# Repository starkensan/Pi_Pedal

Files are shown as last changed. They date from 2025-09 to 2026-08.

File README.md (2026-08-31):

# USB-MIDI-Pedal

RP2040 Zero を使用して、ギター用フットスイッチやエクスプレッションペダルから  
USB-MIDI（CC / PC）メッセージを送信できるデバイスです。  
DAW ソフトやアンプシミュレーター（Amplitube / Helix Native など）で使用できます。

## Features
- USB MIDI（CC / PC）送信対応
- フットスイッチによる CC/PC 切り替え
- エクスプレッションペダル対応（アナログ入力）
- OLED による状態表示
- ノブによる直感的な操作
- ラッチ / モーメンタリ切り替え
- デバウンス処理付き
- コンパクトな RP2040 Zero ベース
- PCB 設計データ & 3D モデル付き

## Product image

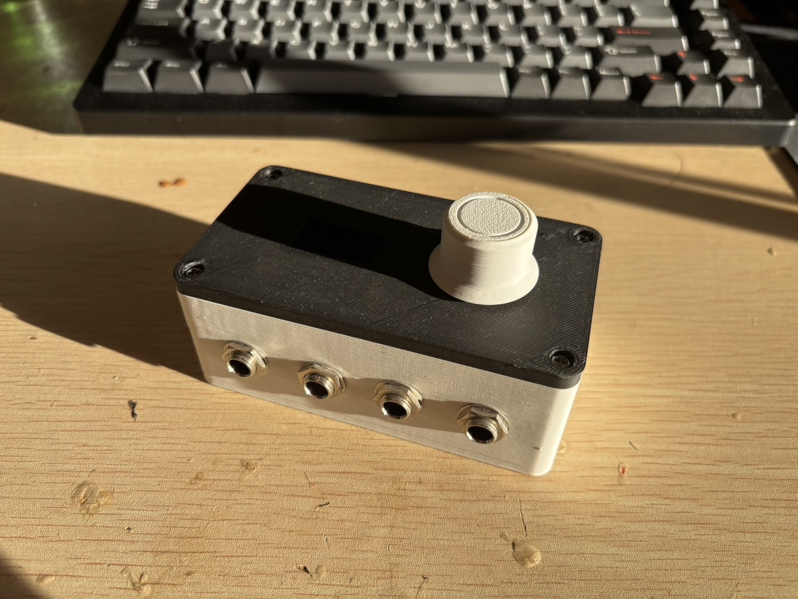
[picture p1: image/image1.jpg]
Prodct_image_1

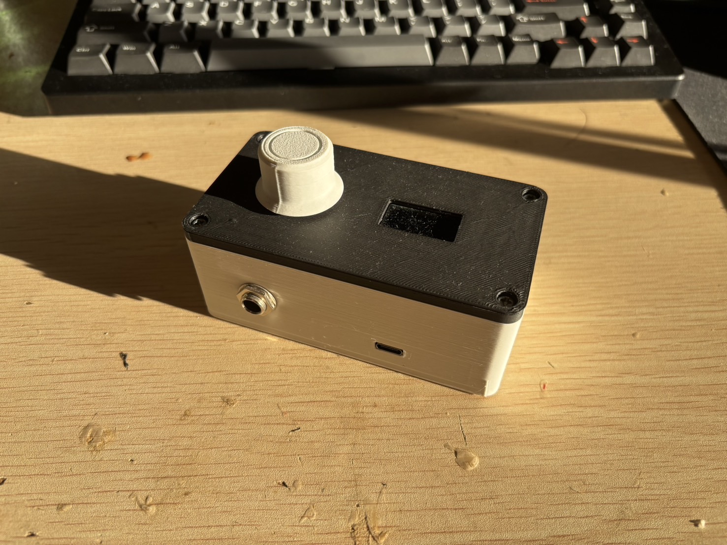
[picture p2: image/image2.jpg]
Prodct_image_2


## Hardware
- **Microcontroller:** RP2040 Zero  
- **Switches:** 1~（自由に拡張可能）  
- **Expression Pedal:** TRS（0〜3.3V）  
- **Display:** 0.96" OLED (I2C)
- **Rotary Encoder** EC11
- **ADC IC** MCP3421
- **その他:** 6.35mm ジャック、TRS、PCB（KiCad）、3Dプリントケース

KiCad の設計データは `hardware/kicad/`、PDF やガーバーファイルなどの生成物は `hardware/exports/`、3D モデルは `3d-models/` に配置しています。

## Software
- **Language:** C++ / Arduino Core RP2040  
- **USB MIDI:** TinyUSB  
- **スイッチ管理:** デバウンス、ラッチ/モーメンタリ対応  
- **表示:** Adafruit SSD1306@^2.5.15

ソフトウェアの構成、MIDI処理、設定メニューの状態遷移は[アーキテクチャドキュメント](docs/ARCHITECTURE.md)を参照してください。

## CI



GitHub Actions で PlatformIO ビルドを自動実行しています。

- ワークフロー: `PlatformIO Build`
- 対象: `pull_request`, `develop` への `push`
- ビルド対象: `pico`, `pico-debug`

PR レビュー時は、`PlatformIO Build` が成功していることを確認してください。

## Build & Upload (CUI / PlatformIO CLI)

本ドキュメントでは、VS Code を使用せず、  
**CUI（ターミナル）から PlatformIO CLI を用いて**  
ビルドおよび RP2040 Zero への書き込みを行う手順を説明します。

### 事前準備

- Python 3.x
- PlatformIO Core（CLI）

#### PlatformIO CLI のインストール

```bash
pip install platformio
````

インストール確認：

```bash
pio --version
```

### ビルド（env:pico）

本プロジェクトでは、通常動作用に `env:pico` を使用します。

```bash
pio run -e pico
```

ビルドが成功すると、以下のディレクトリに成果物が生成されます。

```
.pio/build/pico/
```

### 書き込み（USB / picotool）

RP2040 Zero を USB 接続した状態で、以下を実行します。

```bash
pio run -e pico -t upload
```

### 書き込みに失敗する場合（BOOTSEL モード）

1. RP2040 Zero の **BOOT** ボタンを押しながら USB 接続
2. PC に `RPI-RP2` ドライブが表示されることを確認
3. 再度アップロードを実行

```bash
pio run -e pico -t upload
```

### UF2 ファイルを手動で書き込む方法

PlatformIO による自動書き込みができない場合は、
生成された UF2 ファイルを直接コピーすることで書き込み可能です。

UF2 ファイルの場所：

```
.pio/build/pico/firmware.uf2
```

この `firmware.uf2` を `RPI-RP2` ドライブへ
ドラッグ＆ドロップしてください。

### シリアルモニタ（ログ確認）

```bash
pio device monitor -e pico
```

※ ボーレートは `platformio.ini` にて `115200` に設定されています。

### 接続デバイス一覧の確認

```bash
pio device list
```

### 補足：env の使い分け

* `env:pico`
  通常動作用（USB MIDI / picotool）

* `env:pico-debug`
  CMSIS-DAP を使用したデバッグ用

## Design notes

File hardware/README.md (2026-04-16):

# Hardware

ハードウェア関連ファイルは、編集元と生成物を分けて配置します。

## Directory

- `kicad/`: KiCad の編集元プロジェクト、回路図、PCB、フットプリント
- `exports/pdf/`: 回路図や PCB などの PDF 出力
- `exports/gerber/`: 基板製造用のガーバー、ドリル、製造用パッケージ

## Notes

`exports/gerber/MIDI_Pedal/current/` は KiCad から出力したガーバーファイルです。

`exports/gerber/MIDI_Pedal/fabrication-package/` は、発注や共有に使う製造用パッケージを置く場所です。

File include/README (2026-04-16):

Project-wide public headers are placed in this directory.

Current shared headers:

- `config.h`: firmware-wide pin and feature configuration
- `unity_config.h`: Unity test configuration entry

Policy:

- Keep common headers here when they are used across `src/`, `lib/`, and `test/`.
- Do not add these shared headers under `lib/config/`.

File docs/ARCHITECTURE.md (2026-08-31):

# ソフトウェアアーキテクチャ

このドキュメントは、USB-MIDI Pedal ファームウェアの主要コンポーネント、データの流れ、メニュー操作の状態遷移を説明します。

## 目的と実行環境

RP2040 Zero 上で動作し、フットスイッチとエクスプレッションペダルの入力を USB-MIDI の CC（Control Change）または PC（Program Change）メッセージに変換します。OLED とロータリーエンコーダを使い、各ペダルの設定を本体だけで変更できます。

- 言語／フレームワーク: C++、Arduino Core for RP2040、PlatformIO
- USB MIDI: TinyUSB と MIDI Library
- 設定保存先: EEPROM 互換ストレージ
- 表示: I2C 接続 OLED

## 全体構成

```mermaid
classDiagram
    direction LR

    class Main {
        +setup()
        +loop()
        +setup1()
        +loop1()
    }
    class PedalsController {
        +begin(deviceName)
        +start()
        +update()
        +attachPCCallbacks(callback)
    }
    class MenuController {
        +begin()
        +update()
        +showPCNumber(number)
    }
    class MenuManager {
        +init(menuID)
        +enterSelectedItem()
        +cusorUp()
        +cusorDown()
    }
    class MenuDisplay {
        +render()
        +renderNumber()
    }
    class SettingsManager {
        +begin()
        +getPedalSettings()
        +commitSettings()
        +FactoryReset()
    }
    class Pedal
    class ExpPedal
    class RotaryEncoder
    class DrawDisplay
    class USBMIDI
    class EepromStorage

    Main --> PedalsController
    Main --> MenuController
    PedalsController --> Pedal : foot switch input
    PedalsController --> ExpPedal : expression input
    PedalsController --> USBMIDI : sends CC / PC
    PedalsController --> SettingsManager : reads settings
    MenuController --> RotaryEncoder : receives operation
    MenuController --> MenuManager
    MenuManager --> MenuDisplay
    MenuDisplay --> DrawDisplay : renders OLED
    MenuManager --> SettingsManager : edits settings
    SettingsManager --> EepromStorage : persists settings
```

`Hal*` インターフェース（`HalPedal`、`HalExpPedal`、`HalUSBMIDI`、`HalDisplay`、`HalRotaryEncoder`、`HalStorage`）が、アプリケーション層と具体的なハードウェア実装の間を分離します。このため、nativeテストでは実機の代わりにモックを渡せます。

## 二つの実行ループ

RP2040 の二つのコアを使用し、演奏時のMIDI処理と画面／設定操作を分離します。

```mermaid
flowchart TB
    subgraph Core0[Core 0: MIDI処理]
        A[setup] --> B[SettingsManager.begin]
        B --> C[PedalsController.begin / start]
        C --> D[loop]
        D --> E[PedalsController.update]
        E --> F[フットスイッチ・EXPペダルを更新]
        F --> D
    end

    subgraph Core1[Core 1: UI処理]
        G[setup1] --> H[SettingsManager.begin]
        H --> I[MenuController.begin]
        I --> J[loop1]
        J --> K[PC番号通知があればOLEDへ反映]
        K --> L[ロータリーエンコーダを更新]
        L --> J
    end

    F -. PC番号コールバック .-> K
```

`PedalsController` が PC を送信すると、登録済みコールバックを介して `main.cpp` のPC番号を更新します。Core 1 側はその値を `MenuController` に渡し、メイン画面へ表示します。

## 演奏時の処理

```mermaid
flowchart LR
    Input[入力変化] --> Type{入力種別}
    Type -->|フットスイッチ| Mode{設定されたモード}
    Type -->|EXPペダル| Exp[値を0〜127へ制限]
    Mode -->|CC / Momentary| CC1[押下=127・解放=0のCC]
    Mode -->|CC / Toggle| Toggle[押下ごとにON/OFFを反転してCC]
    Mode -->|PC Next| Next[PC番号を加算し0〜127で循環]
    Mode -->|PC Back| Back[PC番号を減算し0〜127で循環]
    CC1 --> MIDI[USB MIDI送信]
    Toggle --> MIDI
    Next --> MIDI
    Back --> MIDI
    Exp --> MIDI
```

- フットスイッチのデバウンスは `Pedal` が担当します。
- `PedalsController` は `SettingsManager` から各ペダルのモード、MIDIチャンネル、CC番号、スイッチ方式を読み取ります。
- EXPペダルは MCP3421 で読み取り、変化量がしきい値を超えた場合だけ CC を送信します。

## 設定のライフサイクル

```mermaid
stateDiagram-v2
    [*] --> 未初期化
    未初期化 --> EEPROM読込: begin()
    EEPROM読込 --> RAM同期: バージョン一致
    EEPROM読込 --> デフォルト生成: 未初期化・不正
    デフォルト生成 --> RAM同期: EEPROMへ保存
    RAM同期 --> 変更あり: メニューでApply
    変更あり --> RAM同期: Save / commitSettings()成功
    変更あり --> RAM同期: uncommitSettings()
    変更あり --> 変更あり: commitSettings()失敗
```

設定はまず `SettingsManager` 内のRAMに保存されます。メニューの **Apply** はRAMの設定を更新し、**Save** が `commitSettings()` を呼び出してEEPROMへ永続化します。保存前の変更があるかは `dirty_` フラグで管理されます。

## メニュー操作の状態遷移

メニューの実体は `MenuState` に定義された `MenuConfig` と `MenuItem` です。`MenuManager` は「閲覧」と「値変更」の二つの操作モードを管理します。

```mermaid
stateDiagram-v2
    [*] --> Main: 起動
    Main --> Settings: ノブ押下
    Settings --> Submenu: SUBMENUを選択して押下
    Submenu --> Editing: VALUE_CHANGEを選択して押下
    Editing --> Editing: ノブ回転で値を変更
    Editing --> Submenu: 再度ノブ押下
    Submenu --> Submenu: APPLYを押下
    Submenu --> Submenu: SAVEを押下
    Submenu --> Settings: EXITを押下
    Settings --> Main: EXITを押下
```

| 操作 | 閲覧モード | 値変更モード |
| --- | --- | --- |
| ノブ回転 | カーソルを上下に移動 | 選択中パラメータを最小値〜最大値の範囲で変更 |
| ノブ押下 | 項目の種類に応じて遷移・実行 | 値変更モードを終了 |

項目種別は以下です。

| 種別 | 動作 |
| --- | --- |
| `SUBMENU` | 子メニューへ移動 |
| `VALUE_CHANGE` | パラメータ編集モードの開始／終了 |
| `APPLY` | 編集中のパラメータを `SettingsManager` へ反映 |
| `SAVE` | RAM上の設定をEEPROMへ保存 |
| `FUNCTION` | 現在は設定画面からの工場出荷時リセットに使用 |
| `EXIT` | 親メニューへ戻る |

## 関連する主なソース

| 役割 | ファイル |
| --- | --- |
| 起動と2コアループ | `src/main.cpp` |
| MIDI入力の制御 | `src/app/PedalsController/` |
| メニュー入力の制御 | `src/app/MenuController/` |
| メニュー状態・設定反映 | `src/app/MenuManager/` |
| 設定のRAM管理と永続化 | `src/app/SettingsManager/` |
| ハードウェア抽象化 | `lib/Hal/` |
| 実機ドライバ実装 | `lib/Pedal/`, `lib/ExpPedal/`, `lib/USBMIDI/`, `lib/DrawDisplay/`, `lib/EepromStrage/` |

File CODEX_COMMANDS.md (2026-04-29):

# Codex コマンドまとめ

このドキュメントは、`codex-cli 0.125.0` の `--help` 出力をもとに、よく使うコマンドを日本語で整理したものです。

## 基本構文

```bash
codex [OPTIONS] [PROMPT]
codex [OPTIONS] <COMMAND> [ARGS]
```

- サブコマンドを付けない場合は、対話モードで起動します。
- `PROMPT` を渡すと、その内容を最初の指示として開始できます。

例:

```bash
codex
codex "このリポジトリの構成を説明して"
codex -C /path/to/project
```

## よく使う主要コマンド

### 1. 対話モード

```bash
codex
```

- ターミナル上で対話的に Codex を使います。
- サブコマンドなしの標準的な使い方です。

よく併用するオプション:

- `-C, --cd <DIR>`: 作業ディレクトリを指定
- `-m, --model <MODEL>`: 使用モデルを指定
- `-s, --sandbox <MODE>`: サンドボックスモードを指定
- `-a, --ask-for-approval <POLICY>`: コマンド実行時の承認ポリシーを指定
- `--search`: Web 検索を有効化
- `--full-auto`: 低摩擦な自動実行モード

例:

```bash
codex -C . --search
codex -C . -s workspace-write -a on-request
```

### 2. `codex exec`

```bash
codex exec [PROMPT]
```

- 非対話モードで Codex を実行します。
- バッチ処理やスクリプトからの利用に向いています。

例:

```bash
codex exec "READMEを要約して"
echo "変更点をレビューして" | codex exec -
codex exec -o result.txt "このコードの改善点を3つ挙げて"
```

便利なオプション:

- `--json`: JSONL 形式でイベントを出力
- `-o, --output-last-message <FILE>`: 最終メッセージをファイル保存
- `--ephemeral`: セッションをディスクへ保存しない
- `--skip-git-repo-check`: Git 管理外でも実行
- `--ignore-user-config`: ユーザー設定を無視して実行

### 3. `codex review`

```bash
codex review [PROMPT]
```

- コードレビューを非対話で実行します。
- 差分やコミット単位での確認に向いています。

例:

```bash
codex review
codex review --uncommitted
codex review --base main
codex review --commit HEAD~1
codex review "パフォーマンスと安全性を重点的に見て"
```

便利なオプション:

- `--uncommitted`: 未コミット変更をレビュー
- `--base <BRANCH>`: 指定ブランチとの差分をレビュー
- `--commit <SHA>`: 特定コミットの変更をレビュー
- `--title <TITLE>`: レビュー表示用タイトルを指定

### 4. `codex resume`

```bash
codex resume [SESSION_ID]
```

- 以前の対話セッションを再開します。

例:

```bash
codex resume --last
codex resume 123e4567-e89b-12d3-a456-426614174000
codex resume --all
```

便利なオプション:

- `--last`: 直近のセッションを再開
- `--all`: カレントディレクトリ以外のセッションも表示
- `--include-non-interactive`: 非対話セッションも候補に含める

### 5. `codex fork`

```bash
codex fork [SESSION_ID]
```

- 既存セッションを分岐して新しいセッションを作ります。
- 元の会話を残しつつ、別案を試したいときに便利です。

例:

```bash
codex fork --last
codex fork 123e4567-e89b-12d3-a456-426614174000
```

### 6. `codex apply`

```bash
codex apply <TASK_ID>
```

- Codex エージェントが生成した最新 diff を、ローカルのワーキングツリーに `git apply` 形式で反映します。
- Cloud や外部タスク連携後の反映用途で使います。

### 7. `codex login` / `codex logout`

```bash
codex login
codex login status
codex logout
```

- 認証状態の管理を行います。

例:

```bash
codex login status
printenv OPENAI_API_KEY | codex login --with-api-key
codex logout
```

### 8. `codex mcp`

```bash
codex mcp <COMMAND>
```

- 外部 MCP サーバーを管理します。

主なサブコマンド:

- `list`: 一覧表示
- `get`: 設定確認
- `add`: 追加
- `remove`: 削除
- `login`: 認証
- `logout`: 認証解除

例:

```bash
codex mcp list
codex mcp get <name>
```

### 9. `codex plugin`

```bash
codex plugin <COMMAND>
```

- Codex プラグインを管理します。
- 現時点の `--help` では `marketplace` サブコマンドが確認できます。

例:

```bash
codex plugin marketplace --help
```

### 10. `codex completion`

```bash
codex completion [SHELL]
```

- シェル補完スクリプトを生成します。

例:

```bash
codex completion bash
codex completion zsh
codex completion fish
```

### 11. `codex sandbox`

```bash
codex sandbox <COMMAND>
```

- Codex 提供のサンドボックス内でコマンドを実行します。

主なサブコマンド:

- `linux`
- `macos`
- `windows`

例:

```bash
codex sandbox linux --help
```

### 12. `codex features`

```bash
codex features <COMMAND>
```

- フィーチャーフラグの確認や有効化を行います。

主なサブコマンド:

- `list`
- `enable`
- `disable`

例:

```bash
codex features list
```

## そのほかのコマンド

トップレベル `--help` で確認できたコマンド:

- `mcp-server`: Codex を MCP サーバーとして起動
- `app-server`: アプリサーバー関連機能
- `debug`: デバッグ用機能
- `cloud`: Codex Cloud のタスク参照とローカル反映
- `exec-server`: スタンドアロン実行サーバー

必要に応じて、以下で個別ヘルプを確認できます。

```bash
codex <command> --help
```

## よく使うグローバルオプション

多くのコマンドで共通して使えるものです。

- `-c, --config <key=value>`: 設定値の上書き
- `--enable <FEATURE>`: 機能を有効化
- `--disable <FEATURE>`: 機能を無効化
- `-m, --model <MODEL>`: モデル指定
- `-p, --profile <CONFIG_PROFILE>`: プロファイル指定
- `-i, --image <FILE>`: 初期入力に画像を添付
- `-h, --help`: ヘルプ表示
- `-V, --version`: バージョン表示

例:

```bash
codex -V
codex -m gpt-5 -C .
codex -c model="gpt-5" -c shell_environment_policy.inherit=all
```

## サンドボックスと承認ポリシー

### `--sandbox`

実行モード:

- `read-only`
- `workspace-write`
- `danger-full-access`

例:

```bash
codex -s read-only
codex -s workspace-write
```

### `--ask-for-approval`

承認ポリシー:

- `untrusted`
- `on-failure`  
  非推奨。ヘルプ上でも `DEPRECATED` とされています。
- `on-request`
- `never`

例:

```bash
codex -a on-request
codex exec -a never "このディレクトリを解析して"
```

## まず使うならこの3つ

### 対話で使う

```bash
codex
```

### 非対話で1回だけ実行する

```bash
codex exec "やってほしいこと"
```

### 差分レビューをする

```bash
codex review --uncommitted
```

## 補足

- コマンド体系はバージョンによって変わる可能性があります。
- 詳細は常に `codex --help` と `codex <subcommand> --help` を優先してください。

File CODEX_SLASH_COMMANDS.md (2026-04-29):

# Codex スラッシュコマンドまとめ

このドキュメントは、Codex CLI の対話モードで使える `/` から始まるスラッシュコマンドをまとめたものです。

- 主な出典: OpenAI 公式ドキュメント「Slash commands in Codex CLI」
- 確認日: 2026-04-29
- 参考: `codex-cli 0.125.0`

公式ドキュメント:

- https://developers.openai.com/codex/cli/slash-commands

## 基本

対話モードで `/` を入力すると、スラッシュコマンドの候補を開けます。

```bash
codex
```

- スラッシュコマンドは対話モード専用です。
- `codex exec` のような非対話モードでは、通常はそのまま文字列として扱われます。
- タスク実行中でも、コマンドによっては `Tab` で次ターンにキューできます。

## よく使うコマンド

### セッション操作

- `/clear`: 画面をクリアして新しい会話を開始
- `/new`: 同じ CLI セッション内で新しい会話を開始
- `/resume`: 保存済み会話を再開
- `/fork`: 現在の会話を分岐
- `/quit`: CLI を終了
- `/exit`: CLI を終了（`/quit` と同じ）

### モデルと動作

- `/model`: 使用モデルや推論強度を変更
- `/fast`: Fast mode の on/off/status 切り替え
- `/personality`: 応答スタイルを変更
- `/plan`: Plan mode に切り替え、必要ならそのまま計画を指示
- `/permissions`: 承認ポリシーを変更
- `/status`: 現在のモデル、承認設定、トークン使用状況などを表示

### 作業補助

- `/diff`: Git の差分を表示
- `/review`: ワーキングツリーをレビュー
- `/compact`: 会話を要約してコンテキストを節約
- `/copy`: 直近の完了済み出力をコピー
- `/mention`: ファイルやフォルダを会話に添付
- `/init`: `AGENTS.md` のひな形を生成

### 拡張機能まわり

- `/apps`: Apps / connectors を参照してプロンプトに挿入
- `/plugins`: インストール済み・発見可能なプラグインを表示
- `/mcp`: 利用可能な MCP ツールを表示
- `/agent`: サブエージェントのスレッドを切り替え

### 設定・診断

- `/debug-config`: 設定レイヤーやポリシーの診断情報を表示
- `/statusline`: ステータスライン表示項目を設定
- `/title`: ターミナルタイトル表示項目を設定
- `/experimental`: 実験的機能の切り替え
- `/feedback`: ログ送信などのフィードバック用途

### バックグラウンド端末

- `/ps`: バックグラウンド端末の状態表示
- `/stop`: バックグラウンド端末を停止

## コマンド一覧

| コマンド | 概要 | 主な用途 |
| --- | --- | --- |
| `/permissions` | 承認ポリシーを変更 | 自動実行の強さを変えたいとき |
| `/sandbox-add-read-dir` | 追加の読み取りディレクトリを許可 | Windows で追加パスを読ませたいとき |
| `/agent` | アクティブなエージェントスレッドを切り替え | サブエージェントの会話を見たいとき |
| `/apps` | Apps / connectors を参照 | 接続先をプロンプトに付けたいとき |
| `/plugins` | プラグイン一覧を表示 | 利用可能なプラグインを確認したいとき |
| `/clear` | 画面をクリアして新しい会話を開始 | 見た目も会話もリセットしたいとき |
| `/compact` | 会話を要約して圧縮 | 長い会話でコンテキスト節約したいとき |
| `/copy` | 直近の完了済み出力をコピー | 出力をすぐ貼り付けたいとき |
| `/diff` | Git 差分を表示 | 変更内容を確認したいとき |
| `/exit` | CLI 終了 | `/quit` の別名 |
| `/experimental` | 実験的機能を切り替え | 試験機能を有効化したいとき |
| `/feedback` | フィードバック送信 | ログや診断を送りたいとき |
| `/init` | `AGENTS.md` を生成 | 永続的な指示ファイルを作りたいとき |
| `/logout` | ログアウト | 認証情報を外したいとき |
| `/mcp` | MCP ツール一覧を表示 | 外部ツール接続を確認したいとき |
| `/mention` | ファイルやフォルダを添付 | 特定ファイルを読ませたいとき |
| `/model` | モデルを変更 | モデルや reasoning を切り替えたいとき |
| `/fast` | Fast mode 切り替え | 速度優先にしたいとき |
| `/plan` | Plan mode へ切り替え | 実装前に計画を立てたいとき |
| `/personality` | 応答スタイルを変更 | 説明の雰囲気を変えたいとき |
| `/ps` | バックグラウンド端末を表示 | 長時間実行コマンドの様子を見たいとき |
| `/stop` | バックグラウンド端末を停止 | 実行中ジョブを止めたいとき |
| `/fork` | 会話を分岐 | 別案を並行で試したいとき |
| `/resume` | 保存済み会話を再開 | 前回作業の続きをしたいとき |
| `/new` | 新しい会話を開始 | 同じ CLI 内で別タスクに移りたいとき |
| `/quit` | CLI 終了 | セッションを閉じたいとき |
| `/review` | ワーキングツリーをレビュー | 変更の問題点を洗いたいとき |
| `/status` | 現在設定と利用状況を表示 | モデルや承認設定を確認したいとき |
| `/debug-config` | 設定診断を表示 | `config.toml` の効き方を確認したいとき |
| `/statusline` | ステータスライン設定 | 下部表示を調整したいとき |
| `/title` | ターミナルタイトル設定 | タイトル表示を調整したいとき |

## エイリアスと補足

- `/exit` は `/quit` と同じです。
- `/approvals` はまだエイリアスとして使えますが、公式ドキュメントでは「スラッシュ候補一覧には表示されない」とされています。
- `/clean` は `/stop` のエイリアスです。
- `/sandbox-add-read-dir` は Windows ネイティブ実行時のみ利用可能です。
- `/personality` は、使用中モデルが personality 指示をサポートしない場合は表示されないことがあります。
- `/plan` は、タスク実行中は一時的に使えない場合があります。

## よく使う例

### モデルを切り替える

```text
/model
```

### 現在の設定を確認する

```text
/status
```

### 長い会話を圧縮する

```text
/compact
```

### 差分を見る

```text
/diff
```

### 新規会話に切り替える

```text
/new
```

### `AGENTS.md` を作る

```text
/init
```

## まず覚えるならこの5つ

- `/model`
- `/status`
- `/diff`
- `/compact`
- `/init`

## 補足

- スラッシュコマンドは Codex CLI のバージョンで増減する可能性があります。
- 正式な最新情報は、必ず公式ドキュメントを確認してください。

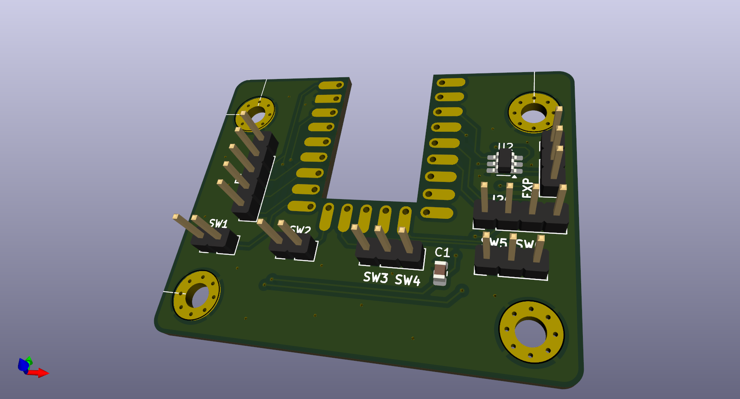
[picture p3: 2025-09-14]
image/PCB-3D.png

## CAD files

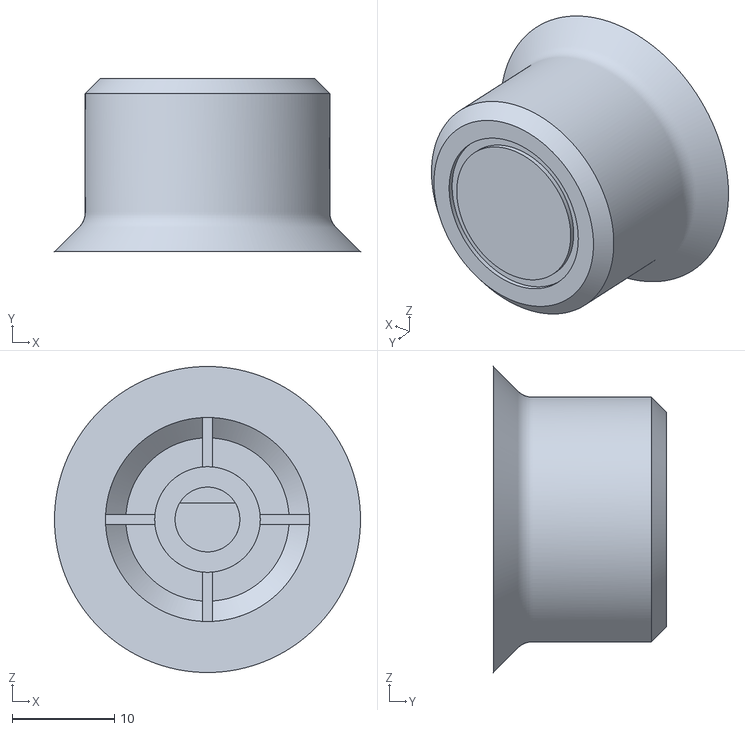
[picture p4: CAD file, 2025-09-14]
3d-models/Knob_cover.stl
30.0 x 17.0 x 30.0

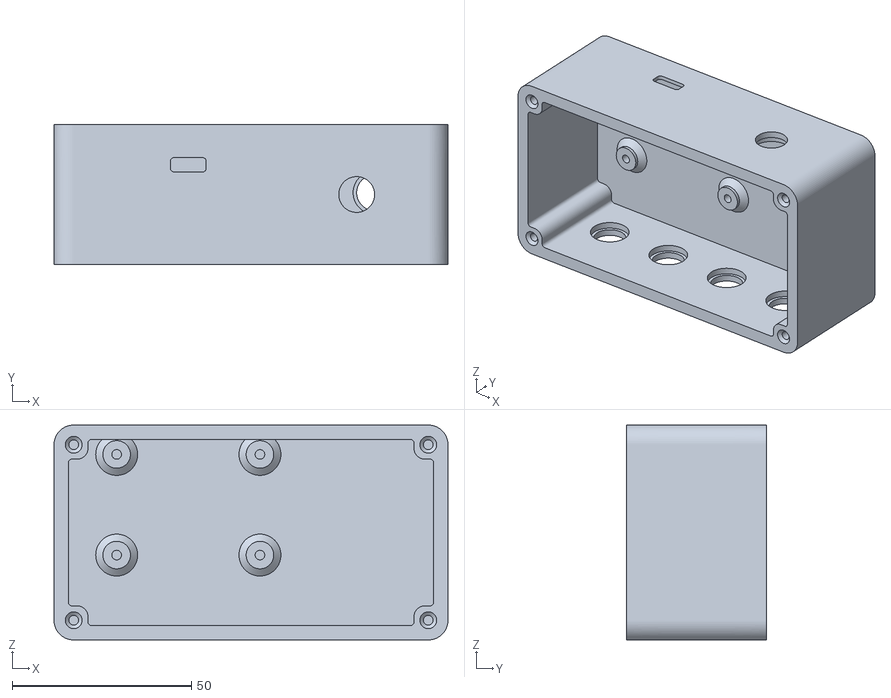
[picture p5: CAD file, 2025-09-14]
3d-models/PedalBox_body.stl
110.0 x 39.0 x 60.0

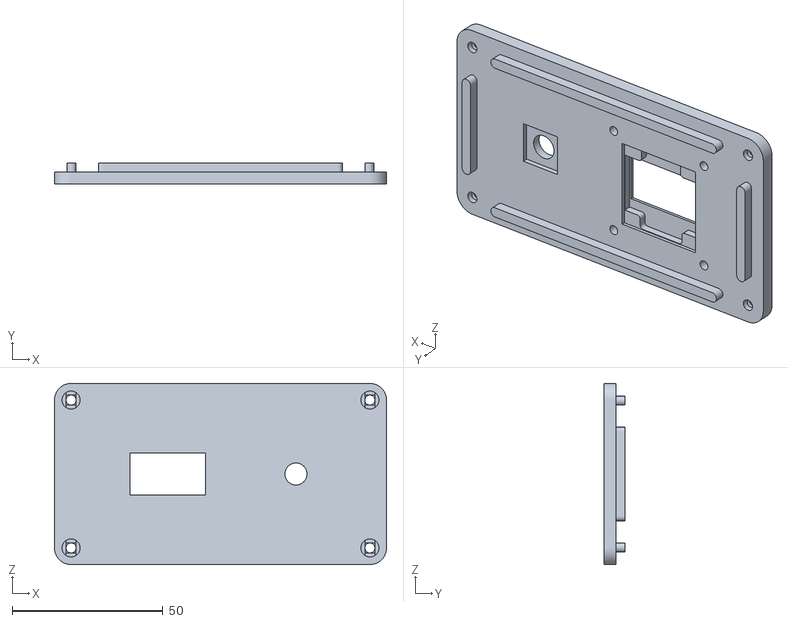
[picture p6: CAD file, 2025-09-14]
3d-models/PedalBox_top.stl
110.0 x 7.00 x 60.0

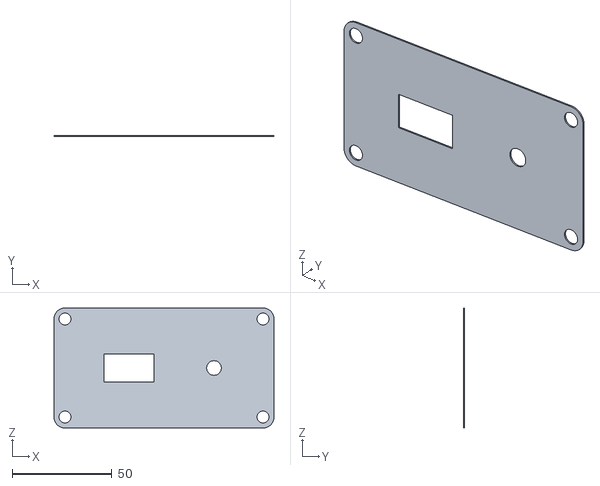
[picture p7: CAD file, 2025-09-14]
3d-models/PedalBox_top2.stl
110.0 x 0.6 x 60.0

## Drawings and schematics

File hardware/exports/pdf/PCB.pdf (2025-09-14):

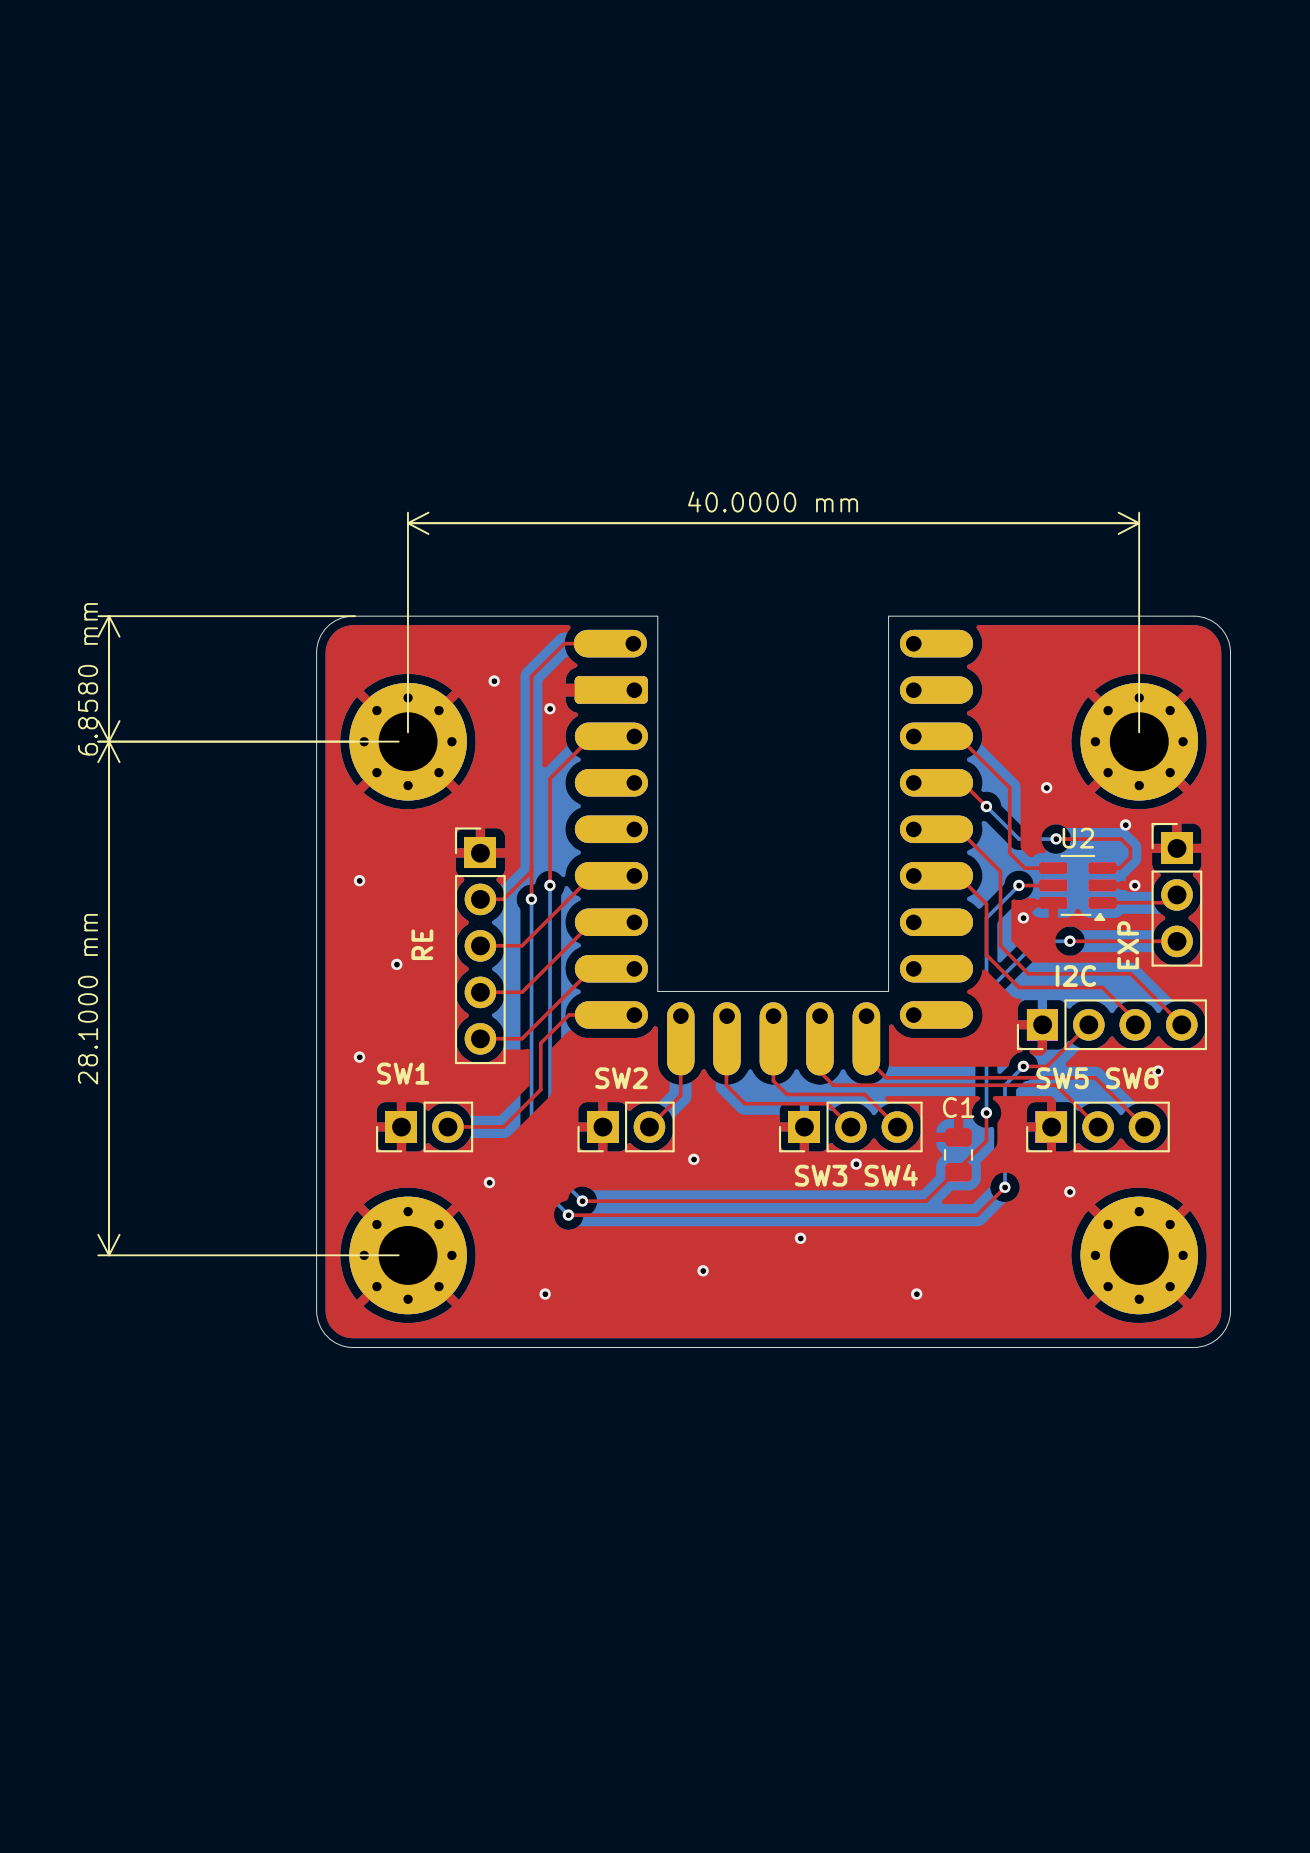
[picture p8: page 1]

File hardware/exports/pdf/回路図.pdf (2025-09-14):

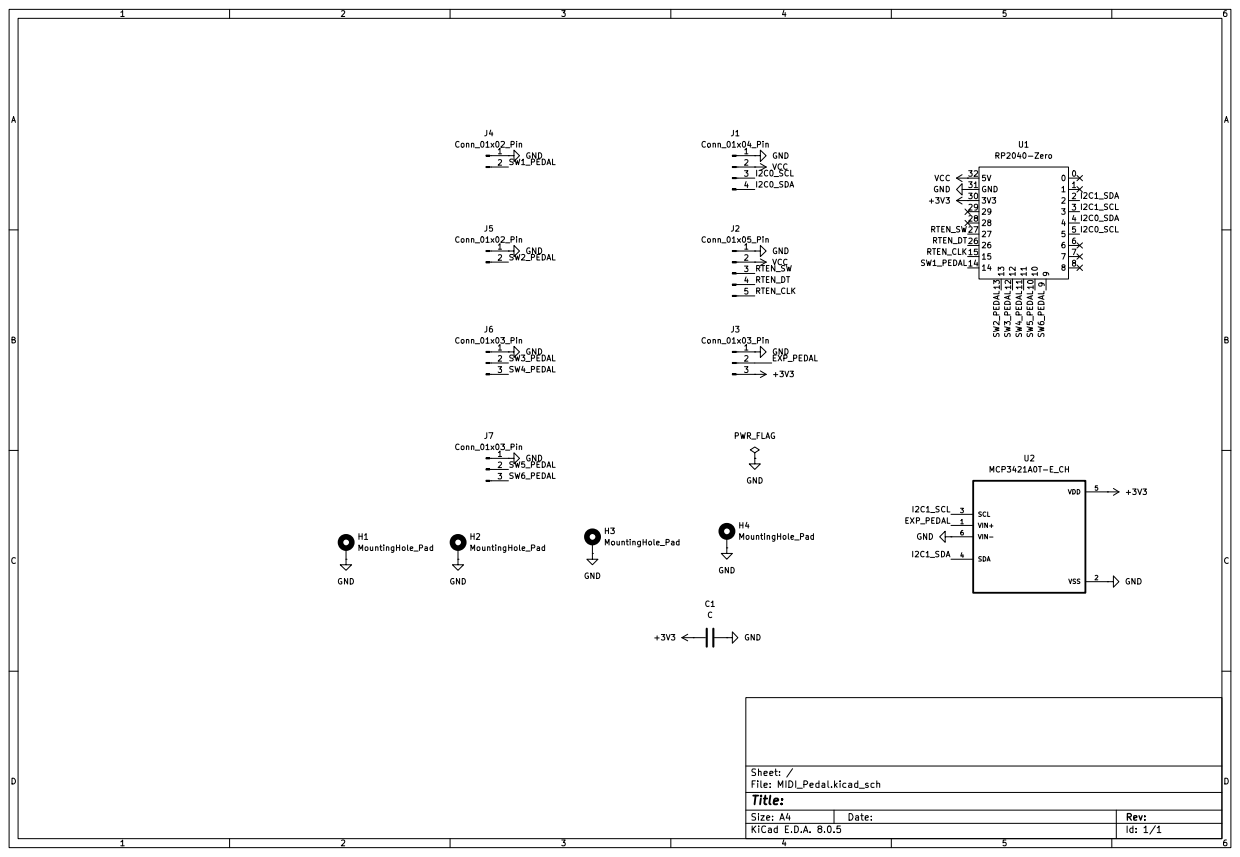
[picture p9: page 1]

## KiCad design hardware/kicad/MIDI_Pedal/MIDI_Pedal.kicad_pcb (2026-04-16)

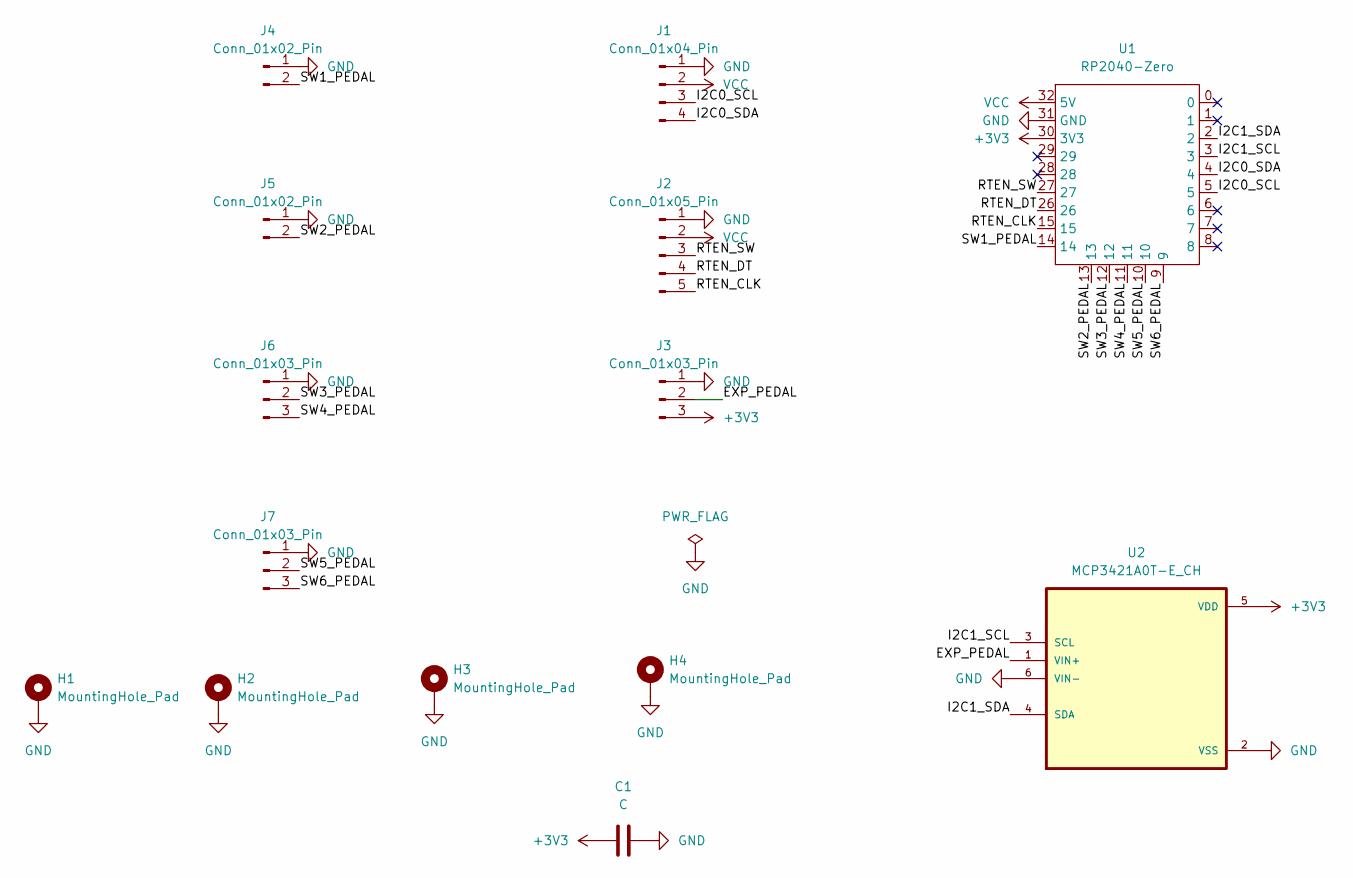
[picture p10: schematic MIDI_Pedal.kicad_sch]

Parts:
C1: C; C_0805_2012Metric
H1, H2, H3, H4: MountingHole_Pad; MountingHole_3.2mm_M3_Pad_Via
J1: Conn_01x04_Pin; PinHeader_1x04_P2.54mm_Vertical
J2: Conn_01x05_Pin; PinHeader_1x05_P2.54mm_Vertical
J3, J6, J7: Conn_01x03_Pin; PinHeader_1x03_P2.54mm_Vertical
J4, J5: Conn_01x02_Pin; PinHeader_1x02_P2.54mm_Vertical
U1: RP2040-Zero; RP2040-Zero-SMD
U2: MCP3421A0T-E_CH; SOT-23-6_Handsoldering

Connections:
+3V3: C1.1, J3.3, U1.30 (3V3), U2.5 (VDD)
/EXP_PEDAL: J3.2, U2.1 (VIN+)
/I2C0_SCL: J1.3, U1.5
/I2C0_SDA: J1.4, U1.4
/I2C1_SCL: U1.3, U2.3 (SCL)
/I2C1_SDA: U1.2, U2.4 (SDA)
/RTEN_CLK: J2.5, U1.15
/RTEN_DT: J2.4, U1.26
/RTEN_SW: J2.3, U1.27
/SW1_PEDAL: J4.2, U1.14
/SW2_PEDAL: J5.2, U1.13
/SW3_PEDAL: J6.2, U1.12
/SW4_PEDAL: J6.3, U1.11
/SW5_PEDAL: J7.2, U1.10
/SW6_PEDAL: J7.3, U1.9
GND: C1.2, H1.1, H2.1, H3.1, H4.1, J1.1, J2.1, J3.1, J4.1, J5.1, J6.1, J7.1, U1.31 (GND), U2.2 (VSS), U2.6 (VIN-)
VCC: J1.2, J2.2, U1.32 (5V)

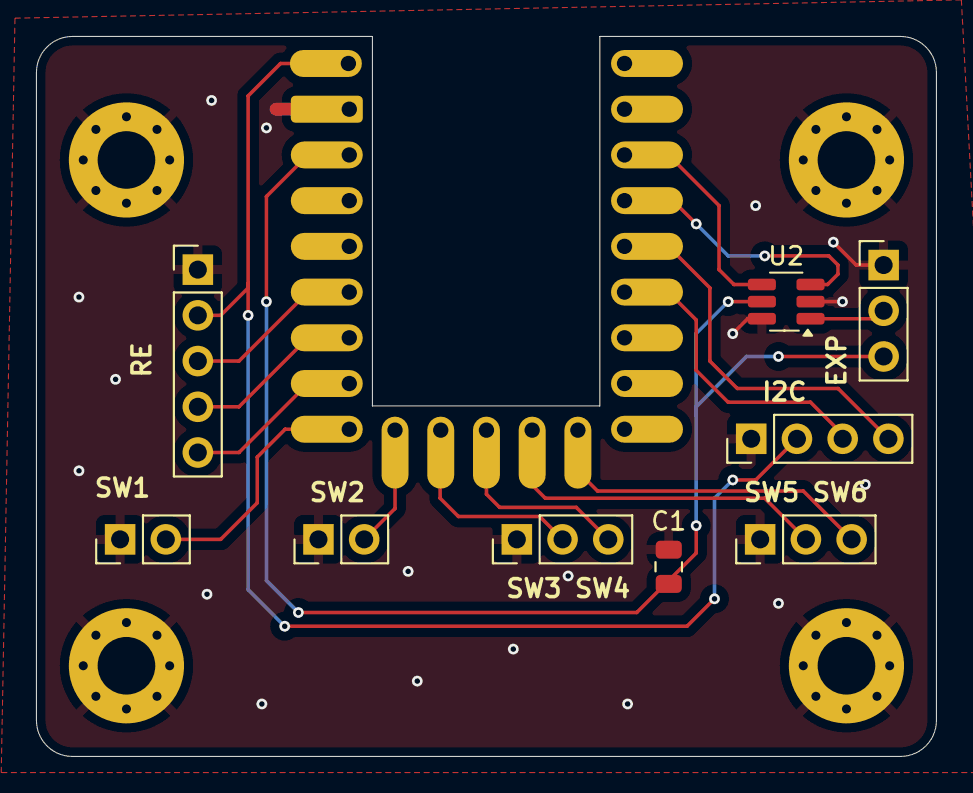
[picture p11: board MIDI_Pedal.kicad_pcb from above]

Board: 2 copper layers, 50.0 x 40.0 mm, 14 parts (0 on the bottom side), 17 nets.

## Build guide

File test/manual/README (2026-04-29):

# Manual Tests

`test/manual/` には、RP2040 Zero や周辺デバイスを接続して確認する手動テストを置きます。

現在の既存テストスイートはすべて manual に分類しています。CI/native 環境では `test/manual/**` を実行対象から除外します。

manual テストを実行する場合は、必要な実機を接続し、対象スイートを明示してください。

```bash
pio test -e pico -f manual/test_display
```

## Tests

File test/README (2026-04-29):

# Test Layout

`test/` は PlatformIO Test Runner 用のテストを置くディレクトリです。
このリポジトリでは、実機確認用の `manual` と CI/PC 自動実行用の `ci` を明確に分けます。

## Categories

| Category | Path | Purpose | Execution |
| --- | --- | --- | --- |
| manual | `test/manual/` | RP2040 Zero、OLED、I2C、USB MIDI、ペダル、ロータリーエンコーダなどの実機確認 | 必要な実機を接続して手動実行 |
| ci | `test/ci/` | PC/native 環境で安定実行できるユニットテスト | `pio test -e native` |

## Existing Test Suites

現在の既存テストはすべて実機または Arduino 環境に依存するため、`manual` に分類します。

| Suite | Category | Reason |
| --- | --- | --- |
| `test/manual/test_display` | manual | OLED と I2C 接続を前提に描画を確認するため |
| `test/manual/test_exp_pedal` | manual | MCP3421 とエクスプレッションペダル操作を前提にするため |
| `test/manual/test_pedal` | manual | GPIO と物理ペダル操作を前提にするため |
| `test/manual/test_rotary_encoder` | manual | ロータリーエンコーダの物理操作を前提にするため |
| `test/manual/test_st_mg` | manual | EEPROM 実装を使った Arduino 環境での SettingsManager 確認のため |
| `test/manual/test_storage` | manual | EEPROM 実装を使った Arduino 環境での Storage 確認のため |
| `test/manual/test_usbmidi` | manual | TinyUSB/USB MIDI 初期化を前提にするため |

`test/Mocks/` と `test/unity_config.cpp` はテスト補助ファイルです。単独のテストスイートではありません。

## Naming Rules

- 実機・手動確認用テストは `test/manual/test_<target>/` に置きます。
- CI/PC 自動実行用テストは `test/ci/test_<target>/` に置きます。
- `<target>` は対象モジュール名を小文字の snake_case で表します。
- 1 テストスイートにつき `test_main.cpp` を 1 つ置きます。

## CI Exclusion Policy

CI/native テスト環境を追加するときは、`test/manual/**` を CI 実行対象から除外します。
`platformio.ini` の `env:native` は以下の方針で設定します。

```ini
[env:native]
test_filter =
	ci/*
test_ignore =
	manual/*
```

CI/PC 向けテストは以下で実行します。

```bash
pio test -e native
```

manual テストを実行する場合は、対象スイートを明示して実行します。

```bash
pio test -e pico -f manual/test_display
```

CI に追加できるのは、実機接続・手動操作・時間待ちに依存せず、PC/native 環境で再現可能なテストだけです。

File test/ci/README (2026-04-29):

# CI Tests

`test/ci/` には、PC/native 環境で安定して自動実行できるテストを置きます。

現時点では CI 向けテストスイートは未追加です。新規に追加する場合は、`test/ci/test_<target>/test_main.cpp` の形式で作成します。

CI に含めるテストは、実機接続、手動操作、USB/I2C/GPIO の実デバイスに依存しないものに限定します。

CI/PC 向けテストは以下で実行します。

```bash
pio test -e native
```

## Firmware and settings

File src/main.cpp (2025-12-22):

#include <Arduino.h>
#include <config.h>

#include <Pedal.hpp>
#include <ExpPedal.hpp>
#include <USBMIDI.hpp>

#include <DrawDisplay.hpp>
#include <RotaryEncoder.hpp>

#include <EepromStorage.hpp>

#include <SettingsManager/SettingsManager.hpp>

#include <PedalsController/PedalsController.hpp>

#include <MenuController/MenuController.hpp>

Pedal pedal;
ExpPedal expPedal;
USBMIDI usbmidi;
EepromStorage storage;

DrawDisplay display(&OLED_I2C_INSTANCE, SDA0_PIN, SCL0_PIN);
RotaryEncoder rotaryEncoder(DT_PIN, CLK_PIN, RE_SW_PIN);

SettingsManager settings(storage);

PedalsController pedals(pedal, expPedal, usbmidi, settings);
MenuController menuController(display, rotaryEncoder, settings);

mutex_t mtx_;

struct LockGuard {
    mutex_t& m;
    LockGuard(mutex_t& m_) : m(m_) { mutex_enter_blocking(&m); }
    ~LockGuard() { mutex_exit(&m); }
};

int PCCurrentNumber_ = 0;
bool PC_flag = false;

void pcNumberCallback(int pcNumber){
    PCCurrentNumber_ = pcNumber;
    PC_flag = true;
}

void setup(){
    settings.begin();
    pedals.attachPCCallbacks(pcNumberCallback);
    pedals.begin("PiPedals");
    pedals.start();
}

void loop(){
    pedals.getPCCurrentNumber();
    pedals.update();
}

void setup1() {
    delay(3000);
    settings.begin();
    menuController.begin();
}

void loop1() {
    if(PC_flag) {
        menuController.showPCNumber(PCCurrentNumber_);
        PC_flag = false;
    }
    menuController.update();
}

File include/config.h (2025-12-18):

#ifndef CONFIG_H
#define CONFIG_H

#define MCP_I2C_INSTANCE Wire1

#define OLED_I2C_INSTANCE Wire

#define PEDAL_COUNT 6
#define EXP_PEDAL_COUNT 1
#define MAX_PEDALS (PEDAL_COUNT + EXP_PEDAL_COUNT)

#define DRAW_MENU_MAX_ITEMS 3

#define EXP_CH 0

#define CLK_PIN 15
#define DT_PIN 26
#define RE_SW_PIN 27

#define SCL1_PIN 3
#define SDA1_PIN 2

#define SCL0_PIN 5
#define SDA0_PIN 4

#define PEDAL1_PIN 13
#define PEDAL2_PIN 14
#define PEDAL3_PIN 10
#define PEDAL4_PIN 9
#define PEDAL5_PIN 12
#define PEDAL6_PIN 11

#define WS2812_PIN 16

#endif

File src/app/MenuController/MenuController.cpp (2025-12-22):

#include "MenuController.hpp"

MenuController* MenuController::self = nullptr;

void MenuController::begin() {
    rotaryEncoder_.attachRotaryCallback(staticRotaryCallback);
    rotaryEncoder_.attachSwitchCallback(staticSwitchCallback);
    menuManager_.init(MenuID::MAIN);
    menuManager_.showPCNumber(0);
}

void MenuController::update() {
    rotaryEncoder_.checkEncoder();
    rotaryEncoder_.checkSwitch();
}

void MenuController::staticRotaryCallback(int direction, int count) {
    if (self) {
        self->RotaryCallback(direction, count);
    }
}

void MenuController::staticSwitchCallback() {
    if (self) {
        self->SwitchCallback();
    }
}

void MenuController::RotaryCallback(int direction, int count) {
    if(direction > 0) {
        menuManager_.cusorDown(count);
    } else if(direction < 0) {
        menuManager_.cusorUp(-count);
    }
}

void MenuController::SwitchCallback() {
    menuManager_.enterSelectedItem();
}

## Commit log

2025-09-14 USBでフットペダルやエクスプレッションペダルを操作できるようにする
    [Knob_cover.stl, PedalBox_body.stl, PedalBox_top.stl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]
2025-09-14 [環境] platformio.initの変更 - 書き込みができるように変更
2025-09-14 [修正] ディレクトリの整理とDrawMenuの実装 - ディレクトリをDriverとlibに分割 - mainに処理内容を書かないようにDrawMenuを実装
    [config.h, main.cpp]
2025-10-20 [変更] ファイル構成の変更
    - ハードウェアを直接操作するdriverディレクトリの追加
    - driverをラッピングするinterfacesディレクトリの追加
    - interfacesまたはdriverを使用し制御するcontrolディレクトリの追加
2025-10-20 [Add] メニュー描画をするクラスの追加
2025-10-21 [Add] メニュー描画をするクラスの追加
    - DrawDisplayクラスの追加
    - DebugLogによるデバック出力の追加
    - DrawDisplayの単体テストの追加
2025-10-21 [Fix] ペダル監視クラスの修正
    - Pedal.hではmidiを扱わないように修正
    - Pedal.hのテストを追加
    [test_main.cpp]
2025-10-21 [Fix] ExpPedalクラスの修正
    - ExpPedal.hではmidiを扱わないように修正
    - ExpPedal.hのテストを追加
    [main.cpp, test_main.cpp]
2025-10-21 [Fix] ペダル監視クラスの修正
    - RotaryEncoder.hのテストの追加
    [test_main.cpp]
2025-10-21 [Fix] ハードウェアコントローラーのインターフェイス化
    - DrawDisplayのインターフェイスクラスのIDisplayの追加
    - ExpPedalのインターフェイスクラスのIExpPedalの追加
2025-10-25 [Add] EepromStorageクラスの追加
    - 設定保存用のEepromStrageクラスの追加
    - テスト実行時リンカエラーが出る現象の修正
    [main.cpp, test_main.cpp]
2025-10-25 [Add] EepromStorageクラスの追加
2025-10-25 [Add] USB MIDIラッピングクラスの実装 refs #1221
2025-10-26 [Fix] ハードウェアコントローラーのインターフェイス化
    - 各ドライバライブラリの抽象化ライブラリの追加
    [test_main.cpp]
2025-10-27 [Fix] ハードウェアコントローラーのインターフェイス化
2025-10-27 [Add] 設定管理クラスの追加
2025-10-30 [Fix] ペダル監視クラスを複数のペダルに対応
2025-11-02 [Fix] 設定管理クラスの修正
    - crc機能の削除
    [test_main.cpp]
2025-11-04 [Add] PedalsControllerクラスの追加
2025-11-21 [Fix] SettingControllerのペダル設定が反映されない現象の修正
2025-11-30 [Fix] 設定管理クラスのCRCの削除
2025-12-02 [Add] PedalsControllerクラスの追加 - ペダル管理用のクラスを追加 - セッティングバージョンを1に変更
2025-12-02 [ADD]PCB-CADファイルの追加
    [MIDI_Pedal-B_Cu.gbr, MIDI_Pedal-B_Mask.gbr, MIDI_Pedal-B_Paste.gbr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]
2025-12-03 [ADD]SettingsManagerの排他制御の追加
    - PedalControllerとメニュー描画でSettingsManagerを使うことを考慮して排他制御の追加
2025-12-03 [ADD]メニュー管理クラスの追加
2025-12-05 [Fix]設定管理クラスの設定項目の名前空間化
    - Settings,PedalSettings, SwitchBehavior, PedalModeを名前空間SettingsDefsに移動
    - ioメソッドの追加
2025-12-16 [ADD] メニュー描画クラスの追加
2025-12-18 [Add]メニュー制御クラスの追加
2025-12-19 [Fix] [ADD]メニュー管理クラスのパラーメーター管理構造体の変更
2025-12-21 [Fix]メニュー管理クラスでインデックスの管理もするように修正
2025-12-21 [Fix] メニュー描画クラスをMenuManagerの修正に適用
2025-12-22 [Fix[ メニュー描画クラスをコンストラクタでパラーメーターを渡すように修正
    - MenuMangerの初期化時はパラーメーターIDで起動画面を指定するように変更
2025-12-22 [Fix] 設定管理クラスの初期化タイミングの調整
2025-12-22 [Add] mainへのメニューの実装
2025-12-22 [Add] メインメニューでPCの現在の番号を表示
2025-12-25 [Update] Readmeのセットアップ手順の追加
2026-04-15 docs: コミットメッセージ規約を追加
2026-04-15 docs: PRタイトル規約を追加
2026-04-15 chore: 生成物のignore設定を追加
2026-04-15 docs: PRテンプレートを追加
2026-04-15 docs: ハードウェア配置説明を修正
2026-04-16 chore: KiCadバックアップを管理対象から削除
2026-04-16 chore: ハードウェア構成を整理
    [MIDI_Pedal-B_Cu.gbr, MIDI_Pedal-B_Mask.gbr, MIDI_Pedal-B_Paste.gbr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]
2026-04-16 chore: 共通ヘッダをincludeに統一
2026-04-16 refactor: アプリモジュール配置を整理
2026-04-16 chore: PlatformIOビルドCIを追加
2026-04-16 fix: CIで共通ヘッダの探索パスを補完
2026-04-16 chore: PlatformIOキャッシュ戦略を追加
2026-04-16 docs: READMEにCI運用情報を追加
2026-04-16 chore: CIをソース変更時のみ実行
2026-04-29 chore: PlatformIOビルドCI運用を補強 #58
2026-04-29 test: manual/ciテスト分類ルールを追加 #64
2026-04-29 test: nativeテスト環境を追加 #66
2026-04-29 test: SettingsManagerをnativeテスト可能に分離 #65
2026-04-29 refactor: 設定依存をSettingsStoreへ分離 #71
2026-08-31 docs: ソフトウェアアーキテクチャを追加
